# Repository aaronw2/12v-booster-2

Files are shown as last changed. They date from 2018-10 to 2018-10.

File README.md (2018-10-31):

# 12v-booster-2
Second generation 5V to 12V booster

My first generation booster was severely limited in the amount of current it could produce. This second generation is designed to handle 2A.

J2 is the input with the following pin designations:
1: +5V
2: +5V
3: GND
4: GND
5: GND
6: PWM_CTL - this drives the PWM mosfet gate with a 100K pull-down

J1 is the output with the following pin designations:
1: +12V
2: +12V
3: GND
4: GND
5: GND
6: PWM output pulled to ground when PWM_CTL is high

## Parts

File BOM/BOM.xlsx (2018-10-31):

Refs | Value | Footprint | Quantity | MFR | MPN | SPR | SPN
Q2 | Si4421DY | Aaron:SOIC127P600X175-8N | 1 | Vishay | SI4421DY-T1-E3 | Digikey | SI4421DY-T1-E3CT-ND
U1 | TPS611781RNW | Aaron:Texas_13_3.0x3.5mm_VQFN_Hotrod_Pitch_0.5mm | 1 | Texas Instruments | TPS611781RNWR | Digikey | 296-48313-1-ND
C5 | 0.018uF | Capacitor_SMD:C_0603_1608Metric | 1 | Kemet | C0603C183J3RAC7867 | Digikey | 399-17400-6-ND
C4 | 0.1uF | Capacitor_SMD:C_0603_1608Metric | 1 | Samsung | CL10B104KO8WPNC | Digikey | 1276-6582-1-ND
C6 | 3.3uF | Capacitor_SMD:C_0603_1608Metric | 1 | TDK | C1608X5R1V335K080AC | Digikey | 445-14167-1-ND
C2 | 4.7uF | Capacitor_SMD:C_0603_1608Metric | 1 | TDK | C1608X5R1E475K080AC | Digikey | 445-9050-1-ND
C3 | 680pF | Capacitor_SMD:C_0603_1608Metric | 1 | Wurth | 885012206107 | Digikey | 732-12237-1-ND
C7;C8;C9 | 22uF | Capacitor_SMD:C_0805_2012Metric | 3 | TDK | C2012X5R1V226M125AC | Digikey | 445-14428-1-ND
C1;C10 | 68uF | Capacitor_SMD:C_1206_3216Metric | 2 | Vishay | C3216X5R1A686M160AC | Digikey | 445-14673-1-ND
J2;J1 | Conn_01x06 | Connector_PinHeader_2.54mm:PinHeader_1x06_P2.54mm_Vertical | 2 | - | - | - | -
L1 | 0.068uH | Inductor_SMD:L_Vishay_IHLP-2020 | 1 | Vishay-Dale | IHLP2020BZERR68M01 | Digikey | 541-1086-1-ND
Q1 | BSS214NW | Package_TO_SOT_SMD:SOT-323_SC-70 | 1 | Infineon | BSS214NWH6327XTSA1 | Digikey | BSS214NWH6327XTSA1CT-ND
R1 | 100K | Resistor_SMD:R_0603_1608Metric | 1 | Yageo | RC0603JR-07100KL | Digikey | 311-100KGRCT-ND
R5 | 162K | Resistor_SMD:R_0603_1608Metric | 1 | Vishay-Dale | TNPW0603162KBEEA | Digikey | 541-3170-1-ND
R4 | 44.2K | Resistor_SMD:R_0603_1608Metric | 1 | Yageo | RC0603FR-0744K2L | Digikey | 311-44.2KHRCT-ND
R3 | 68.1K | Resistor_SMD:R_0603_1608Metric | 1 | Yageo | RC0603FR-0768K1L | Digikey | 311-68.1KHRCT-ND
R6 | 732K | Resistor_SMD:R_0603_1608Metric | 1 | Yageo | RC0603FR-07732KL | Digikey | 311-732KHRCT-ND
R7 | 80.6K | Resistor_SMD:R_0603_1608Metric | 1 | Vishay-Dale | CRCW060380K6FKEA | Digikey | 541-80.6KHCT-ND
R2 | 88.7K | Resistor_SMD:R_0603_1608Metric | 1 | Yageo | RC0603FR-0788K7L | Digikey | 311-88.7KHRCT-ND

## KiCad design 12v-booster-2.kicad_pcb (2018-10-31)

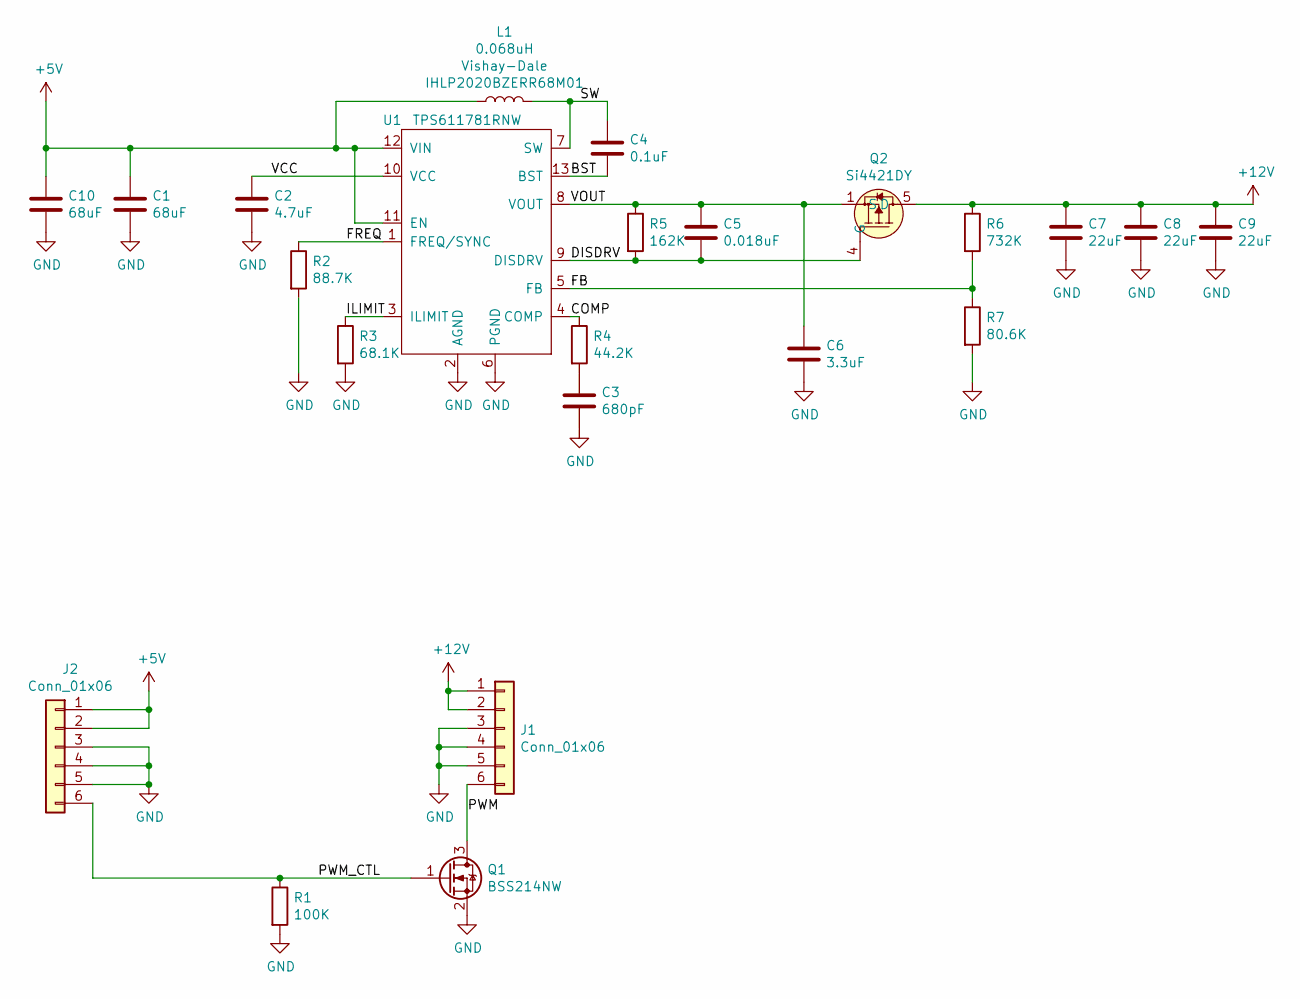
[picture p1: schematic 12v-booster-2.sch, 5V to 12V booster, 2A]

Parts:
C1, C10: 68uF; C_1206_3216Metric; MPN C3216X5R1A686M160AC
C2: 4.7uF; C_0603_1608Metric; MPN C1608X5R1E475K080AC
C3: 680pF; C_0603_1608Metric; MPN 885012206107
C4: 0.1uF; C_0603_1608Metric; MPN CL10B104KO8WPNC
C5: 0.018uF; C_0603_1608Metric; MPN C0603C183J3RAC7867
C6: 3.3uF; C_0603_1608Metric; MPN C1608X5R1V335K080AC
C7, C8, C9: 22uF; C_0805_2012Metric; MPN C2012X5R1V226M125AC
J1, J2: Conn_01x06; PinHeader_1x06_P2.54mm_Vertical
L1: 0.068uH; L_Vishay_IHLP-2020; MPN IHLP2020BZERR68M01
Q1: BSS214NW; SOT-323_SC-70; MPN BSS214NWH6327XTSA1
Q2: Si4421DY; SOIC127P600X175-8N; MPN SI4421DY-T1-E3
R1: 100K; R_0603_1608Metric; MPN RC0603JR-07100KL
R2: 88.7K; R_0603_1608Metric; MPN RC0603FR-0788K7L
R3: 68.1K; R_0603_1608Metric; MPN RC0603FR-0768K1L
R4: 44.2K; R_0603_1608Metric; MPN RC0603FR-0744K2L
R5: 162K; R_0603_1608Metric; MPN TNPW0603162KBEEA
R6: 732K; R_0603_1608Metric; MPN RC0603FR-07732KL
R7: 80.6K; R_0603_1608Metric; MPN CRCW060380K6FKEA
U1: TPS611781RNW; Texas_13_3.0x3.5mm_VQFN_Hotrod_Pitch_0.5mm; MPN TPS611781RNWR

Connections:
+5V: C1.1, C10.1, J2.1, J2.2, L1.1, U1.11 (EN), U1.12 (VIN)
+12V: C7.1, C8.1, C9.1, J1.1, J1.2, Q2.5 (D), Q2.6 (D), Q2.7 (D), Q2.8 (D), R6.1
/BST: C4.2, U1.13 (BST)
/COMP: R4.1, U1.4 (COMP)
/DISDRV: C5.2, Q2.4 (G), R5.2, U1.9 (DISDRV)
/FB: R6.2, R7.1, U1.5 (FB)
/FREQ: R2.1, U1.1 (FREQ/SYNC)
/ILIMIT: R3.1, U1.3 (ILIMIT)
/PWM: J1.6, Q1.3 (D)
/PWM_CTL: J2.6, Q1.1 (G), R1.1
/SW: C4.1, L1.2, U1.7 (SW)
/VCC: C2.1, U1.10 (VCC)
/VOUT: C5.1, C6.1, Q2.1 (S), Q2.2 (S), Q2.3 (S), R5.1, U1.8 (VOUT)
GND: C1.2, C2.2, C3.2, C6.2, C7.2, C8.2, C9.2, C10.2, J1.3, J1.4, J1.5, J2.3, J2.4, J2.5, Q1.2 (S), R1.2, R2.2, R3.2, R7.2, U1.2 (AGND), U1.6 (PGND)
unnamed: C3.1, R4.2

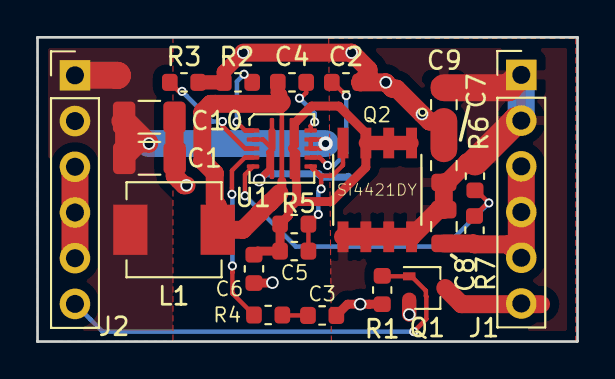
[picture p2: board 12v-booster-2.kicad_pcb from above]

Board: 2 copper layers, 30.0 x 16.9 mm, 23 parts (0 on the bottom side), 15 nets.

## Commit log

2018-10-31 Initial checkin of version 1.0
    [12v-booster-2.kicad_pcb, 12v-booster-2.sch]
2018-10-31 Added missing BOM
    [BOM.csv, BOM.xlsx]
2018-10-31 Increased output to 2A
    [12v-booster-2.kicad_pcb, 12v-booster-2.sch, BOM.csv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]
2018-10-31 Fixed BOM for v1.1.
    [BOM.xlsx]

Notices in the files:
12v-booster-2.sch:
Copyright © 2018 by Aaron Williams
